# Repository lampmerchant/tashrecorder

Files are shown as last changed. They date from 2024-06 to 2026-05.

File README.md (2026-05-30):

# TashRecorder

## Elevator Pitch

It's an audio interface that can be switched between imitating the Farallon MacRecorder, an audio digitizer for vintage Macintosh computers without audio input, and the Apple MIDI Interface, a standard MIDI interface for the Macintosh.  It targets the PIC12F1501 (8 pins, ~$0.96) microcontroller.

## Technical Details

### Connections

```
                      .--------.
              Supply -|01 \/ 08|- Ground
       RxD- <--- RA5 -|02    07|- RA0 <--- MIDI/Audio In
       RxD+ <--- RA4 -|03    06|- RA1 ---> Clock Out
Mode Select ---> RA3 -|04    05|- RA2 ---> LED
                      '--------'
```

Mode Select floats high and selects audio digitizer mode by default; pulling it low selects MIDI interface mode.  The mode can be changed at any time.

The LED output is active high.

### Audio Digitizer Mode

In Audio Digitizer mode, the firmware imitates a Farallon MacRecorder, generating a clock of approximately 358 kHz (one tenth the NTSC color burst frequency), oversampling the input pin at a rate of approximately 44 kHz and transmitting 8-bit samples to the Macintosh at a rate of approximately 22 kHz.

The LED flashes on when the audio has peaked for a set number of consecutive samples (3 by default, changeable by editing the PEAKPWR parameter in firmware).  Peaking is determined by masking off a number of bits (3 by default, changeable by editing the PEAKMSK parameter in firmware) and checking whether the remaining bits are all ones or all zeroes.

### MIDI Interface Mode

In MIDI Interface Mode, the firmware imitates the input of an Apple MIDI Interface, generating a 1 MHz clock (32 times the MIDI baud rate of 31250 Hz) and relaying the input pin's state directly to the RxD pins.  The MIDI input pin's state is inverted before being reflected by the RxD pins; this allows it to be connected directly to the output of an optocoupler such as the 6N138 with the addition of an external pullup resistor.

The LED flashes on when data is being received over the MIDI interface.

### Building Firmware

Building the firmware requires Microchip MPASM, which is included with their development environment, MPLAB.  Note that you **must** use MPLAB X version 5.35 or earlier or MPLAB 8 as later versions of MPLAB X have removed MPASM.

The firmware can also be built using gpasm, an MPASM-compatible assembler that is part of the [gputils](https://gputils.sourceforge.io/) project.  Please note, however, that the release builds are built using MPASM and compatibility with gpasm is not tested.

## Building Your Own

1-Bit Fever Dreams on YouTube has made a helpful [video](https://www.youtube.com/watch?v=QnrPvtYhGZ4) detailing the process of building a TashRecorder using [demik's PCB](https://github.com/lampmerchant/tashrecorder/tree/main/pcb).

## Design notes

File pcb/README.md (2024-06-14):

# TashRecorder

This is a simple (but dense) design, using all through hole components.  It's designed this way to be period correct and easy to build for people who don't like soldering SMT components.

This folder contains the source KiKad files for the main board. Please check the Panels subfolder for the FR-4 front and back plates.

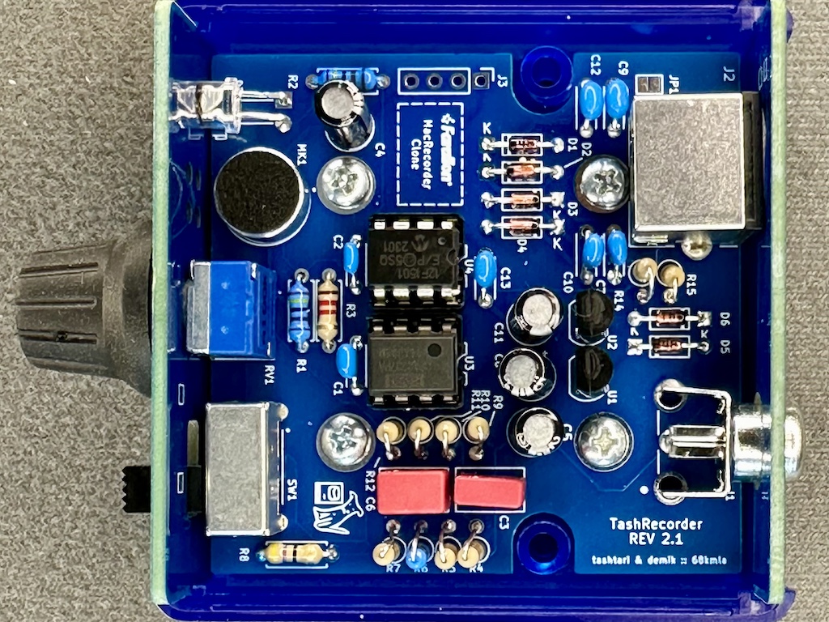
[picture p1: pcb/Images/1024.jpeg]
PCB


## BOM
### Mandatory

Here is the BOM for the main board. Part number are what was tested on prototypes board but you may find alternatives easily, especially resistors and sockets

| Reference(s) | Value | Quantity | Notes | Part number |
|---|---|---|---|---|
| C1, 2, 7, 9-10, 12-13 | 100nF | 7 | ceramic capacitor 5.08mm | Weltron 453358 |
| C3 | 6800pF | 1 | film capacitor 5mm | Wima FKS2G016801B00KSSD  |
| C8 | 680pF | 1 | film capacitor 5mm | Wima FKP2J006801D00HSSD  |
| C4, C5, C8, C11 | 22uF | 4 | aluminium electrolytic capacitor | Panasonic ECA-1HHG220I |
| D1 to D6 | 1N4148 | 6 | general purpose switching diode | Vishay 1N4148-TAP |
| D7 | Red | 1 | High efficiency 20000-30000mcd 5mm LED | TRU TC-10551696 |
| J1 | RCA | 1 | RCA Phono Connector | CUI Devices RCJ-013 |
| J2 | Connector  | 1 | Circular Mini-DIN Connectors 8P | Kycon KMDGX-8S-AS |
| MK1 | Micro | 1 | omnidirectional electret microphone | DB Unlimited MO093803-1  |
| R1, R2, R6 | 2.4kΩ | 3 | standard 0.25W metal film resistor | TRU MF0W4FF2401 |
| R3, R12 | 1.2kΩ | 2 | standard 0.25W carbon film resistor | TRU CFR0W4J0122 |
| R4, R5, R7, R9 | 220kΩ | 4 | standard 0.25W carbon film resistor | TRU CFR0W4J0224 |
| R8, R14, R15 | 47Ω | 3 | standard 0.25W carbon film resistor | TRU CFR0W4J0470 |
| R10 | 4.7kΩ | 1 | standard 0.25W carbon film resistor | TRU CFR0W4J0472 |
| R11 | 10kΩ | 1 | standard 0.25W carbon film resistor | TRU CFR0W4J0103 |
| RV1 | 100kΩ | 1 | audio 100kΩ panel potentiometer | Bourns PTD901-2015K-A104 |
| SW1 | SPDT | 1 | slide switches right angle | E-Switch EG1224 |
| U1, U2 | 2.5V | 2 | 2.5V TO-92-3 20mA voltage reference | ON Semi LM385Z-2.5 |
| U3 | OPA2337 | 1 | low power RR out CMOS op-amp | Texas OPA2337PA |
| U4 | PIC | 1 | 8-bit Microcontrollers DIP PIC12F1501  | MC PIC12F1501-I/P |
| Case | ABS | 1 | Instrument Case, ABS 2.6x2.6" | HM 1593K(TBU\|GY\|BK) |
| PCB Screws | #4 | 4 | Phillips Pan Head screws #4 x 1/4" | SERPAC 6004 |
| Socket | DIP-8 | 2 | DIP-8 socket | TRU TC-A 08-LC-TT-203 |
| Knob | Blue | 1 | knob for Ø 6 mm 18 teeth shafts | PSP 49009-BL |

Using sockets is recommended because it will allow you to reclaim the microcontroler and op-amp. This will also allow you to upgrade the firmware if a future firmware is released.

### BOM (external links)
Here is a complete mouser. It includes lots of 10 when that was cheaper. You may have extra components
- https://www.mouser.fr/ProjectManager/ProjectDetail.aspx?AccessID=31409f3429

## PCBs
Main PCB is 4 layers. Panels are simple 2 layers boards. The gerbers are avaible in the release section.
Check for the following files:
* TashRecorder_2.1.zip: main board revision 2.1
* TashRecorder_back_panel_2.1.zip: FR-4 back panel revision 2.1
* TashRecorder_front_panel_2.1.zip: FR-4 front panel revision 2.1

You should be use any mainstream PCB manufacturer for theses. Nothing special about them. PCB thickness should be 1.6mm

On JLCPCB, select "Specify a location" to the option "Remove Order Number" for all of them

## Building
Building is straightworfard. It's recommended to start with small components first (diodes, then resistor, LED), then other components, and connectors last.
For Japanase mounted resistors, the resistor will go on the circle side

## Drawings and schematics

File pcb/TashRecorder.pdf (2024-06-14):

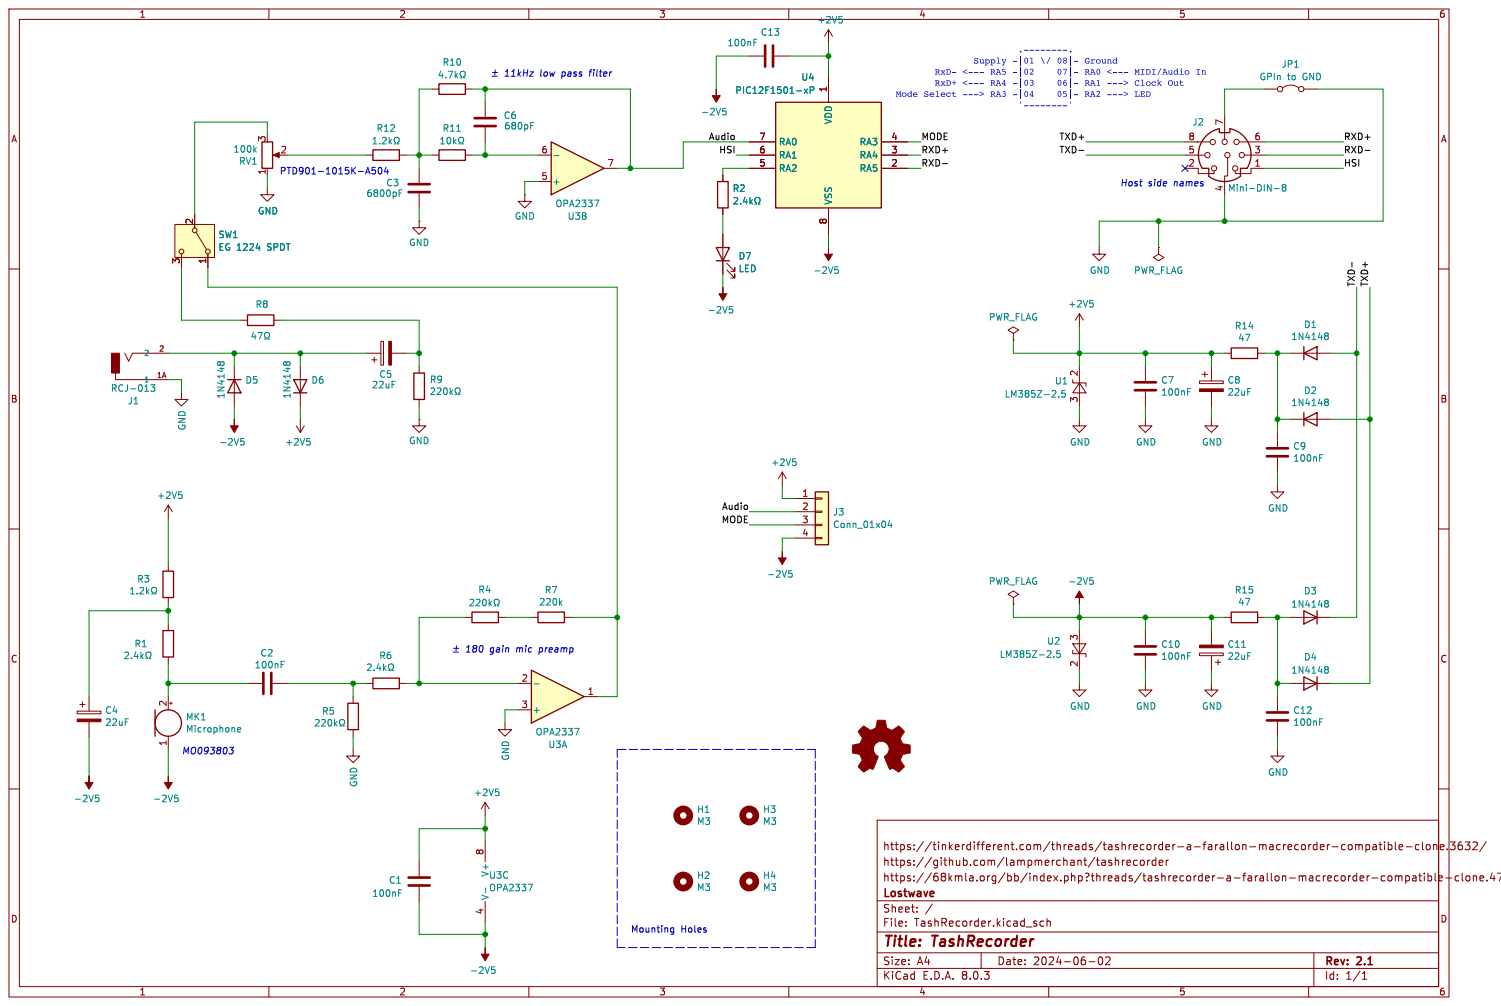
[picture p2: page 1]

Audio HSI Mounting Holes

þÿ±180 gain mic preamp

https://tinkerdifferent.com/threads/tashrecorder-a-farallon-macrecorder-compatible-clone.3632/
https://github.com/lampmerchant/tashrecorder
https://68kmla.org/bb/index.php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
Id: 1/1 Title: TashRecorder File: TashRecorder.kicad_sch Sheet: / Lostwave

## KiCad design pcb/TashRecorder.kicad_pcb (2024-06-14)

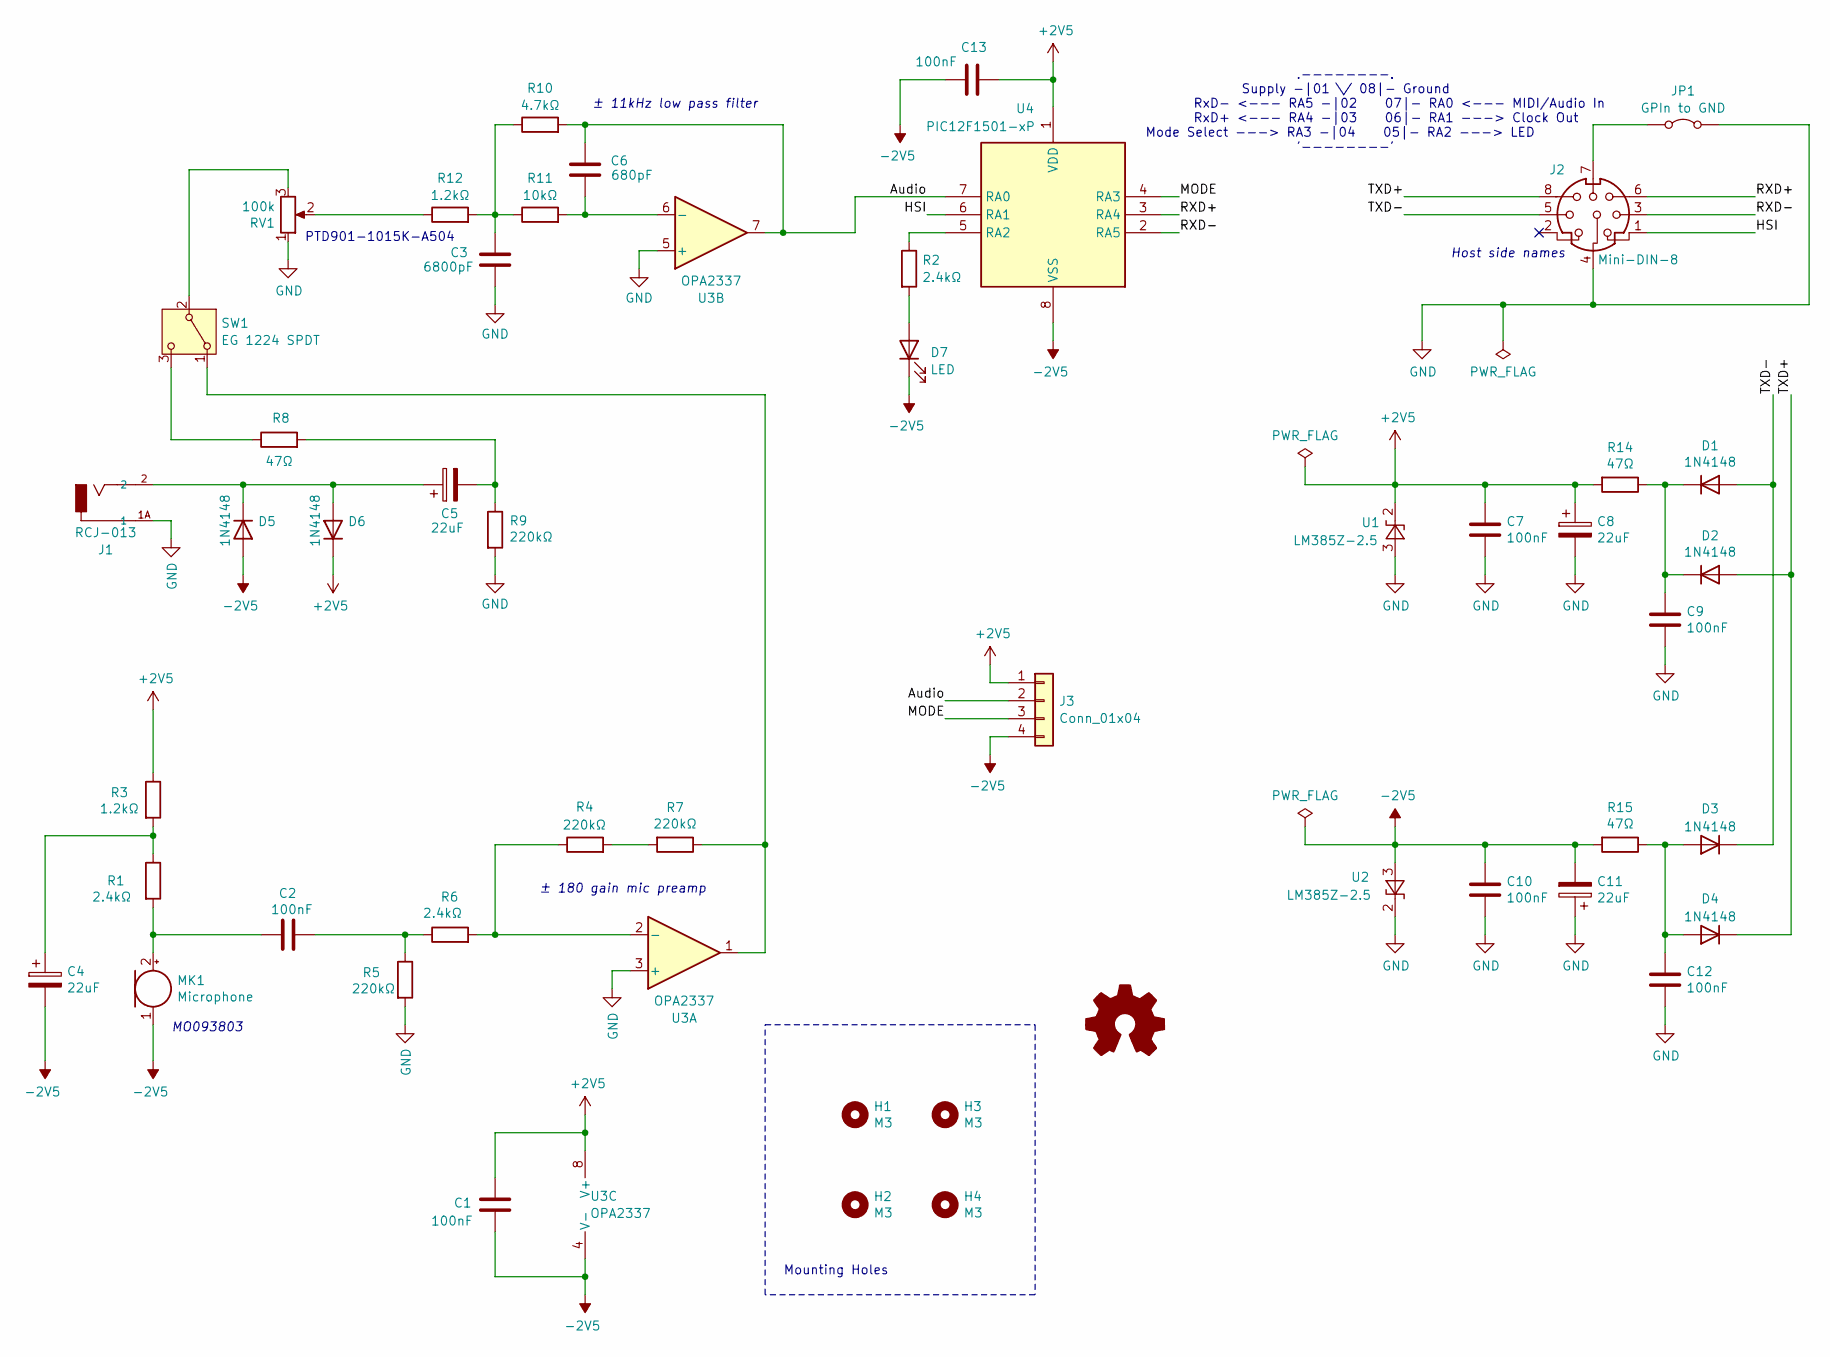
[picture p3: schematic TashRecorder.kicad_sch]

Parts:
C1, C2, C7, C9, C10, C12, C13: 100nF; C_Disc_D4.3mm_W1.9mm_P5.00mm
C3: 6800pF; C_Rect_L7.2mm_W4.5mm_P5.00mm_FKS2_FKP2_MKS2_MKP2
C4, C5, C8, C11: 22uF; CP_Radial_D5.0mm_P2.50mm
C6: 680pF; C_Rect_L7.2mm_W4.5mm_P5.00mm_FKS2_FKP2_MKS2_MKP2
D1, D2, D3, D4, D5, D6: 1N4148; D_DO-35_SOD27_P7.62mm_Horizontal
D7: LED; LED_D5.0mm_Horizontal_O6.35mm_Z9.0mm
H1, H2, H3, H4: M3; MountingHole_3.2mm_M3_Pad
J1: RCJ-013; CUI_RCJ-013; PART_REV B
J2: Mini-DIN-8; 57492681
J3: Conn_01x04; PinHeader_1x04_P2.54mm_Vertical
JP1: GPIn to GND; SolderJumper-2_P1.3mm_Open_Pad1.0x1.5mm
MK1: Microphone; CMA4544PFW
R1, R2: 2.4kΩ; R_Axial_DIN0207_L6.3mm_D2.5mm_P7.62mm_Horizontal
R3: 1.2kΩ; R_Axial_DIN0207_L6.3mm_D2.5mm_P7.62mm_Horizontal
R4, R5, R7, R9: 220kΩ; R_Axial_DIN0207_L6.3mm_D2.5mm_P2.54mm_Vertical
R6: 2.4kΩ; R_Axial_DIN0207_L6.3mm_D2.5mm_P2.54mm_Vertical
R8: 47Ω; R_Axial_DIN0207_L6.3mm_D2.5mm_P7.62mm_Horizontal
R10: 4.7kΩ; R_Axial_DIN0207_L6.3mm_D2.5mm_P2.54mm_Vertical
R11: 10kΩ; R_Axial_DIN0207_L6.3mm_D2.5mm_P2.54mm_Vertical
R12: 1.2kΩ; R_Axial_DIN0207_L6.3mm_D2.5mm_P2.54mm_Vertical
R14, R15: 47Ω; R_Axial_DIN0207_L6.3mm_D2.5mm_P2.54mm_Vertical
RV1: 100k; PTD9011015FA203
SW1: EG 1224 SPDT; EG1224
U1, U2: LM385Z-2.5; TO-92_HandSolder
U3: OPA2337; DIP-8_W7.62mm_LongPads
U4: PIC12F1501-xP; DIP-8_W7.62mm_LongPads

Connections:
+2V5: C1.1, C7.1, C8.1, C13.1, D6.1 (K), J3.1, R3.1, R14.2, U1.2 (K), U3.8 (V+), U4.1 (VDD)
-2V5: C1.2, C4.2, C10.1, C11.2, C13.2, D5.2 (A), D7.1 (K), J3.4, MK1.1 (-), R15.2, U2.3 (A), U3.4 (V-), U4.8 (VSS)
/Audio: C6.2, J3.2, R10.2, U3.7, U4.7 (RA0)
/HSI: J2.1, U4.6 (RA1)
/MODE: J3.3, U4.4 (RA3)
/RXD+: J2.6, U4.3 (RA4)
/RXD-: J2.3, U4.2 (RA5)
/TXD+: D2.2 (A), D4.1 (K), J2.8
/TXD-: D1.2 (A), D3.1 (K), J2.5
GND: C3.2, C7.2, C8.2, C9.2, C10.2, C11.1, C12.2, J1.1A (1), J2.4, JP1.2 (B), R5.2, R9.2, RV1.1, U1.3 (A), U2.2 (K), U3.3 (+), U3.5 (+)
unnamed: C2.2, R5.1, R6.1
unnamed: C3.1, R10.1, R11.1, R12.2
unnamed: C4.1, R1.1, R3.2
unnamed: C5.2, R8.2, R9.1
unnamed: C9.1, D1.1 (K), D2.1 (K), R14.1
unnamed: C12.1, D3.2 (A), D4.2 (A), R15.1
unnamed: C5.1, D5.1 (K), D6.2 (A), J1.2
unnamed: D7.2 (A), R2.2
unnamed: J2.7, JP1.1 (A)
unnamed: C2.1, MK1.2 (+), R1.2
unnamed: R4.2, R7.2
unnamed: R12.1, RV1.2
unnamed: R7.1, SW1.1 (A), U3.1
unnamed: RV1.3, SW1.2 (B)
unnamed: R8.1, SW1.3 (C)
unnamed: R4.1, R6.2, U3.2 (-)
unnamed: C6.1, R11.2, U3.6 (-)
unnamed: R2.1, U4.5 (RA2)

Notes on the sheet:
.--------. Supply -|01 \/ 08|- Ground RxD- <--- RA5 -|02 07|- RA0 <--- MIDI/Audio In RxD+ <--- RA4 -|03 06|- RA1 ---> Clock Out Mode Select ---> RA3 -|04 05|- RA2 ---> LED '--------'
± 11kHz low pass filter
PTD901-1015K-A504
± 180 gain mic preamp
MO093803
Mounting Holes
Host side names

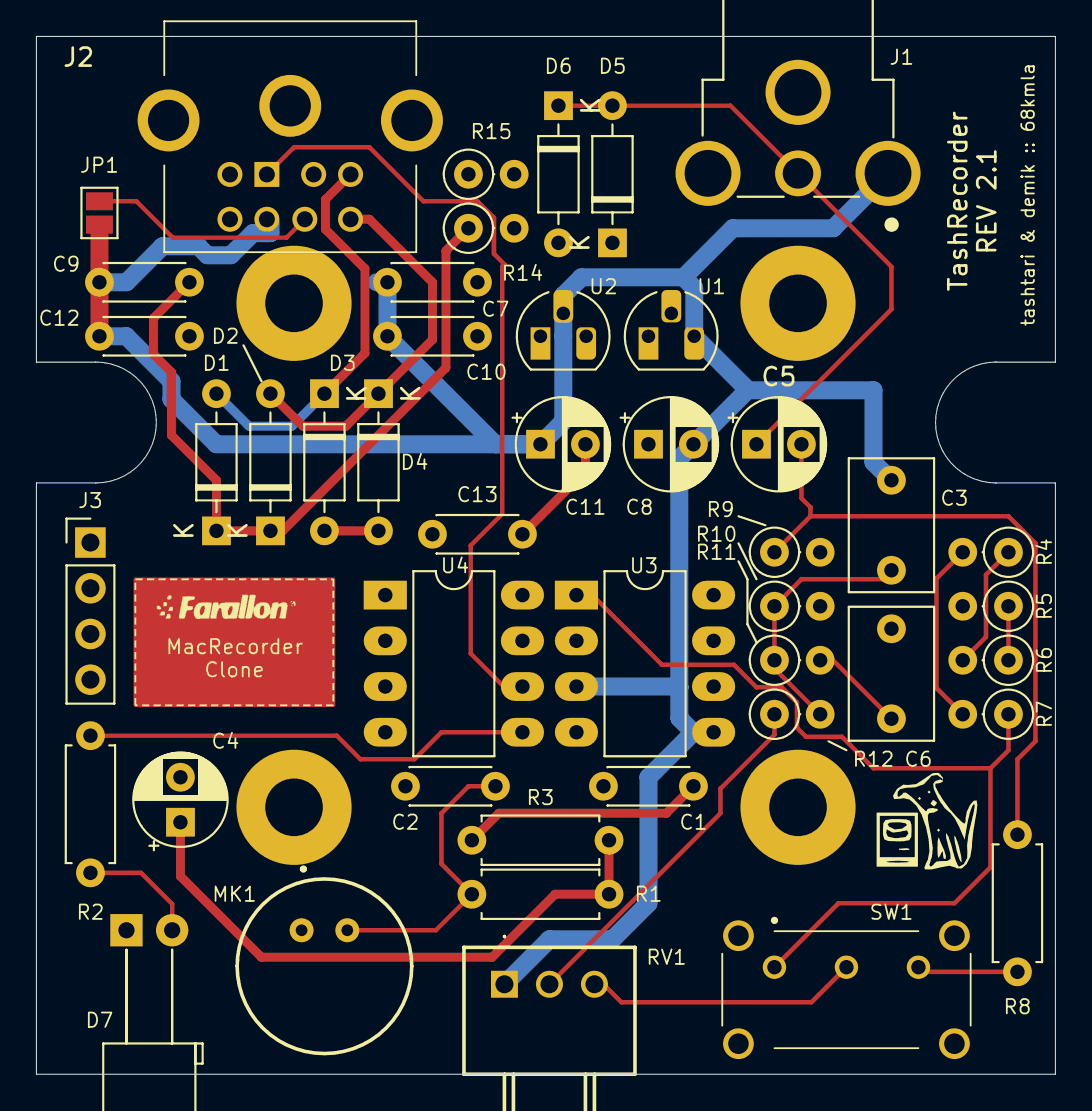
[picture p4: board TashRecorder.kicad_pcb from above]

Board: 4 copper layers, 56.6 x 57.7 mm, 51 parts (1 on the bottom side), 28 nets.

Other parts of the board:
GB: LOGO; Farallon
GF: LOGO; Farallon

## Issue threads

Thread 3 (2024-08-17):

Typo in the BOM list

Mu0n, 2024-08-17:
location: https://github.com/lampmerchant/tashrecorder/tree/main/pcb

the 680 pF film capacitor is called C8 in the list, but it should be C6 instead.

C8 is elsewhere and is an electrolytic cap.

demik, 2024-08-17:
My bad. Fixed with PR #4

lampmerchant, 2024-08-17:
Merged.  Thanks for pointing it out.

Closed 2024-08-17.

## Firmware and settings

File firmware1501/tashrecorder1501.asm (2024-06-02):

;;; 80 characters wide please ;;;;;;;;;;;;;;;;;;;;;;;;;; 8-space tabs please ;;;


;
;;;
;;;;;  TashRecorder
;;;
;


;;; Connections ;;;

;;;                                                            ;;;
;                          .--------.                            ;
;                  Supply -|01 \/ 08|- Ground                    ;
;           RxD- <--- RA5 -|02    07|- RA0 <--- MIDI/Audio In    ;
;           RxD+ <--- RA4 -|03    06|- RA1 ---> Clock Out        ;
;    Mode Select ---> RA3 -|04    05|- RA2 ---> LED              ;
;                          '--------'                            ;
;                                                                ;
;    LED is active high.  Mode Select is MIDI when pulled low    ;
;    and audio digitizer when allowed to float high.             ;
;                                                                ;
;;;                                                            ;;;


;;; Assembler Directives ;;;

	list		P=PIC12F1501, F=INHX32, ST=OFF, MM=OFF, R=DEC, X=ON
	#include	P12F1501.inc
	errorlevel	-302	;Suppress "register not in bank 0" messages
	errorlevel	-224	;Suppress TRIS instruction not recommended msgs
	__config	_CONFIG1, _FOSC_INTOSC & _WDTE_OFF & _PWRTE_ON & _MCLRE_OFF & _CP_OFF & _BOREN_OFF & _CLKOUTEN_OFF
			;_FOSC_INTOSC	Internal oscillator, I/O on RA5
			;_WDTE_OFF	Watchdog timer disabled
			;_PWRTE_ON	Keep in reset for 64 ms on start
			;_MCLRE_OFF	RA3/!MCLR is RA3
			;_CP_OFF	Code protection off
			;_BOREN_OFF	Brownout reset off
			;_CLKOUTEN_OFF	CLKOUT disabled, I/O on RA4
	__config	_CONFIG2, _WRT_OFF & _STVREN_ON & _BORV_LO & _LPBOR_OFF &_LVP_OFF
			;_WRT_OFF	Write protection off
			;_STVREN_ON	Stack over/underflow causes reset
			;_BORV_LO	Brownout reset voltage low trip point
			;_LPBOR_OFF	Low power brownout reset disabled
			;_LVP_OFF	High-voltage on Vpp to program


;;; Macros ;;;

DELAY	macro	value		;Delay 3*W cycles, set W to 0
	movlw	value
	decfsz	WREG,F
	bra	$-1
	endm

DNOP	macro
	bra	$+1
	endm

WAITLAT	macro			;Wait until bit has been latched (BSR must be 0)
	btfss	PIR2,NCO1IF
	bra	$-1
	bcf	PIR2,NCO1IF
	endm


;;; Constants ;;;

;Pin Assignments
INP_PIN	equ	RA0	;MIDI/audio pin
INP_ADC	equ	0 ;AN0	;Audio ADC input
LED_PIN	equ	RA2	;Peak LED pin
SEL_PIN	equ	RA3	;Mode select pin

;Parameters
PEAKPWR	equ	1	;2^n + 1 consecutive samples must peak to turn LED on
PEAKMSK	equ	3	;Mask off n lowest bits before determining peak


;;; Variable Storage ;;;

	cblock	0x70	;Bank-common registers
	
	FLAGS	;You've got to have flags
	SAMPLE	;Next sample to be clocked out
	PEAKCNT	;Counter for number of consecutive samples that have peaked
	X12
	X11
	X10
	X9
	X8
	X7
	X6
	X5
	X4
	X3
	X2
	X1
	X0
	
	endc


;;; Vectors ;;;

	org	0x0		;Reset vector
	goto	Init

	org	0x4		;Interrupt vector
	;fall through


;;; Interrupt Handler ;;;

Interrupt
	bra	$


;;; Common Hardware Initialization ;;;

Init
	banksel	OSCCON		;16 MHz high-freq internal oscillator
	movlw	B'01111000'
	movwf	OSCCON

	banksel	ADCON0		;ADC left justified, Fosc/32, Vref is Vdd,
	movlw	B'00100000'	; source AN0, auto-triggered by Timer2 match
	movwf	ADCON1
	movlw	B'01010000'
	movwf	ADCON2

	banksel	T1CON		;Timer1 ticks 1:8 with instruction clock when
	movlw	B'00110000'	; running
	movwf	T1CON

	banksel	T2CON		;Timer2 ticks with instruction clock, rolls over
	movlw	86		; at a little under half the sample loop length
	movwf	PR2
	movlw	B'00000100'
	movwf	T2CON

	banksel	APFCON		;Move CLC1 to RA4
	movlw	B'00000010'
	movwf	APFCON

	banksel	WPUA		;Weak pullup enabled on mode select only
	movlw	1 << SEL_PIN
	movwf	WPUA

	banksel	OPTION_REG	;Weak pullups enabled
	movlw	B'01111111'
	movwf	OPTION_REG

	banksel	LATA		;Default state of output pins is low
	clrf	LATA

	banksel	TRISA		;RxD, clock, and peak LED output, all other pins
	movlw	B'00001001'	; inputs
	movwf	TRISA

	movlw	high ADRESH	;Initialize key globals
	movwf	FSR0H
	movlw	low ADRESH
	movwf	FSR0L
	movlw	high CLC1POL
	movwf	FSR1H
	movlw	low CLC1POL
	movwf	FSR1L

	movlb	0		;Enter audio digitizer or MIDI initialization
	btfss	PORTA,SEL_PIN	; depending on whether mode select pin is high
	goto	MidiInit	; or low
	;fall through


;;; Audio Digitizer Hardware Initialization ;;;

AudioInit
	banksel	ADCON0		;Turn on ADC, source audio input pin
	movlw	B'00000001' | (INP_ADC << 2)
	movwf	ADCON0

	banksel	CLC1CON		;CLC1 is a DFF clocked by the NCO (its input is
	clrf	CLC1SEL0	; CLC1POL[1]), CLC2 inverts CLC1
	clrf	CLC1SEL1
	clrf	CLC1POL
	movlw	B'01000000'
	movwf	CLC1GLS0
	clrf	CLC1GLS1
	clrf	CLC1GLS2
	clrf	CLC1GLS3
	movlw	B'11000100'
	movwf	CLC1CON
	clrf	CLC2SEL0
	clrf	CLC2SEL1
	clrf	CLC2POL
	movlw	B'00010000'
	movwf	CLC2GLS0
	movwf	CLC2GLS1
	clrf	CLC2GLS2
	clrf	CLC2GLS3
	movlw	B'11000000'
	movwf	CLC2CON

	banksel	NCO1CON		;NCO accumulator increments by 23419 in pulse
	movlw	B'10000000'	; mode, resulting in a clock of approximately
	movwf	NCO1CLK		; 357956 Hz, which is pretty close to one tenth
	movlw	0x5B		; the NTSC color burst frequency, with a pulse
	movwf	NCO1INCH	; width of 16 clocks of the 16 MHz oscillator,
	movlw	0xA3		; interrupting on the rising edge
	movwf	NCO1INCL
	movlw	B'11000001'
	movwf	NCO1CON

	banksel	ANSELA		;Audio input pin analog, all others digital
	movlw	1 << INP_PIN
	movwf	ANSELA

	;fall through


;;; Audio Mainline ;;;

AudioMain
	movlw	0x80		;Load silence for first sample
	movwf	SAMPLE		; "
	movlb	0		;Wait until first ADC sample has been read
	bcf	PIR1,ADIF	; "
	btfss	PIR1,ADIF	; "
	bra	$-1		; "
	;fall through
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

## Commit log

2024-06-13 added PCBs
    [TashRecorder.kicad_pcb, TashRecorder.kicad_sch, tashrecorder_BP.kicad_pcb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]
2024-06-13 added schematic in PDF form
2024-06-14 cleaned BOM
    [TashRecorder.kicad_sch]
2024-06-14 added PCB Readme (BOM, mouser link)
    [tashrecorder_FP.kicad_pcb]
